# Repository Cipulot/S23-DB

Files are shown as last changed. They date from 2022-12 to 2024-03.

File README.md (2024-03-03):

# S23 DB

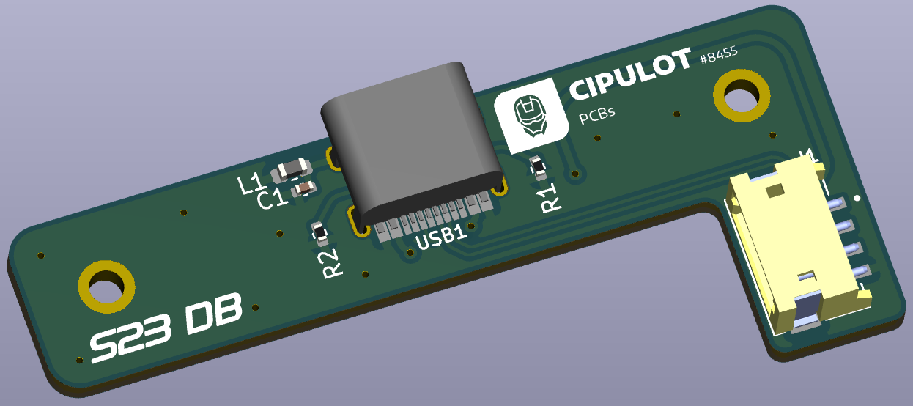
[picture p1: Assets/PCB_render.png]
S23 DB PCB render


S23 daughterboard with CC resistors.

There's not much to be said about this board. It's a daughterboard for the S23 by Sho, with the CC resistors to allow full USB-C operations.

The original JST ZH/ZR connector is replaced with one that has horizontal mount anchor points, to avoid mechanical stress on the connector (LCSC part number C485354).

The pinout is marked on the bottom of the PCB for reference.

## License

<br />This work is licensed under a <a rel="license" href="http://creativecommons.org/licenses/by-nc-sa/4.0/">Creative Commons Attribution-NonCommercial-ShareAlike 4.0 International License</a>.

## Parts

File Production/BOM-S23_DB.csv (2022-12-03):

Comment | Designator | Footprint | LCSC
HRO-TYPE-C-31-M-12 | USB1 | HRO-TYPE-C-31-M-12-Assembly | C165948
5.1k | R1,R2 | R_0402_1005Metric | C25905
100n | C1 | C_0402_1005Metric | C307331
JST | J1 | JST_S4B-ZR-SM4A-TF(LF)(SN) | C485354
220 @ 100MHz, 2A | L1 | L_0603_1608Metric | C85832

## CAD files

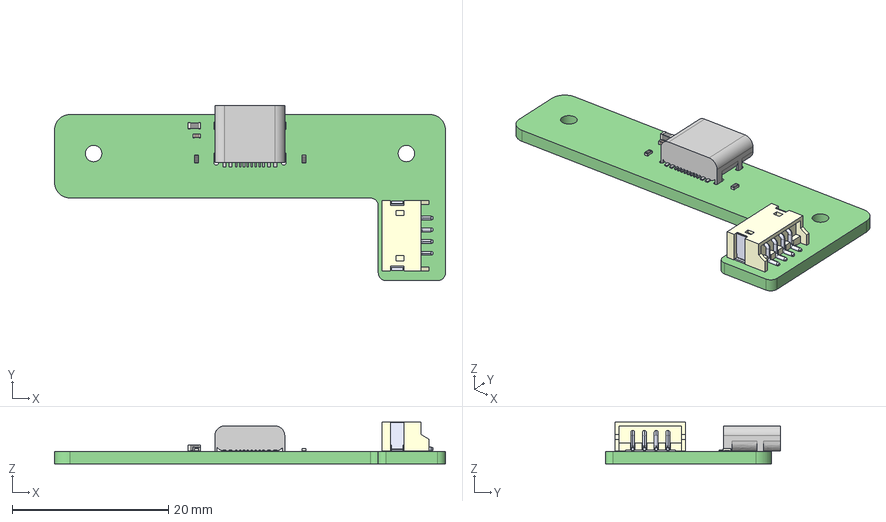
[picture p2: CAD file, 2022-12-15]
Assets/S23_DB.step
50.0 x 22.4 x 5.35 mm
S23_DB PCB

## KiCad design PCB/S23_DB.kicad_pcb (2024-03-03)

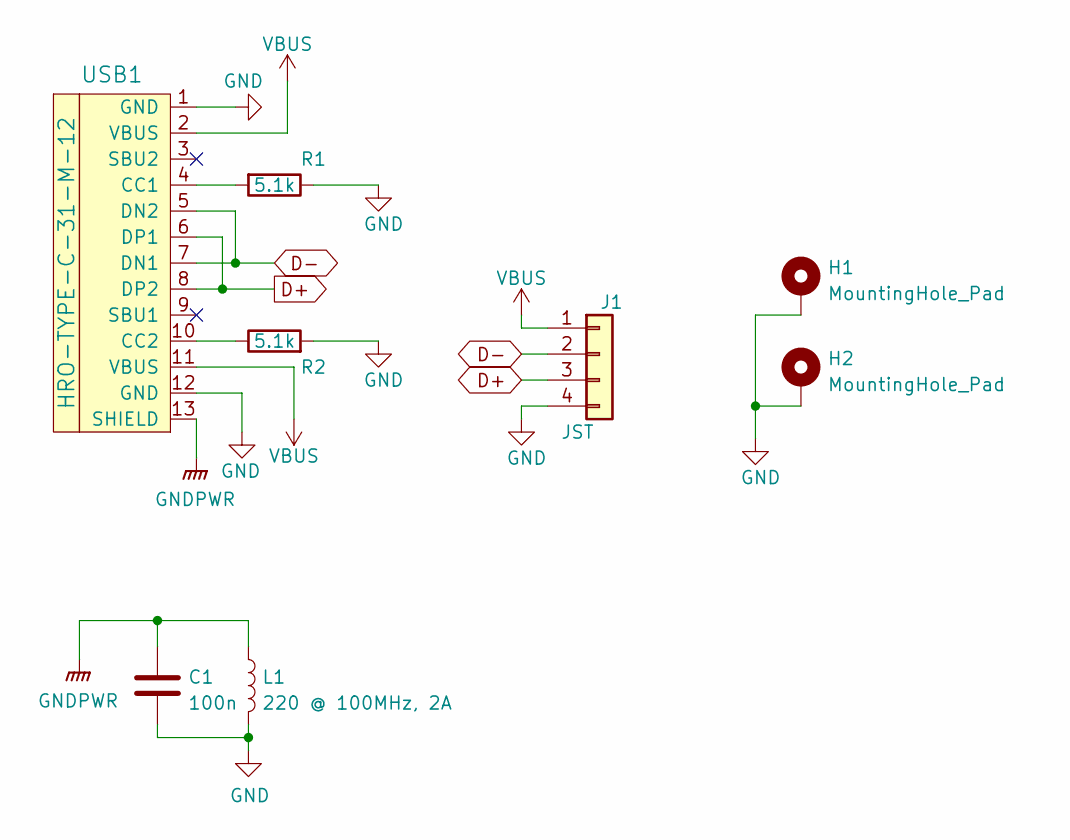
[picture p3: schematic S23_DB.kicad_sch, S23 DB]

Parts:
C1: 100n; C_0402_1005Metric; LCSC C307331
H1, H2: MountingHole_Pad; MountingHole_2.2mm_M2_ISO7380_Pad
J1: JST; JST_S4B-ZR-SM4A-TF(LF)(SN); MPN S4B-ZR-SM4A-TF(LF)(SN); LCSC C485354
L1: 220 @ 100MHz, 2A; L_0603_1608Metric; LCSC C85832
R1, R2: 5.1k; R_0402_1005Metric; LCSC C25905
USB1: HRO-TYPE-C-31-M-12; HRO-TYPE-C-31-M-12-Assembly; LCSC C165948

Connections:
D+: J1.3, USB1.6 (DP1), USB1.8 (DP2)
D-: J1.2, USB1.5 (DN2), USB1.7 (DN1)
GND: C1.2, H1.1, H2.1, J1.4, J1.S1, J1.S2, L1.2, R1.1, R2.2, USB1.1 (GND), USB1.12 (GND)
GNDPWR: C1.1, L1.1, USB1.13 (SHIELD)
unnamed: R1.2, USB1.4 (CC1)
unnamed: R2.1, USB1.10 (CC2)
VBUS: J1.1, USB1.2 (VBUS), USB1.11 (VBUS)

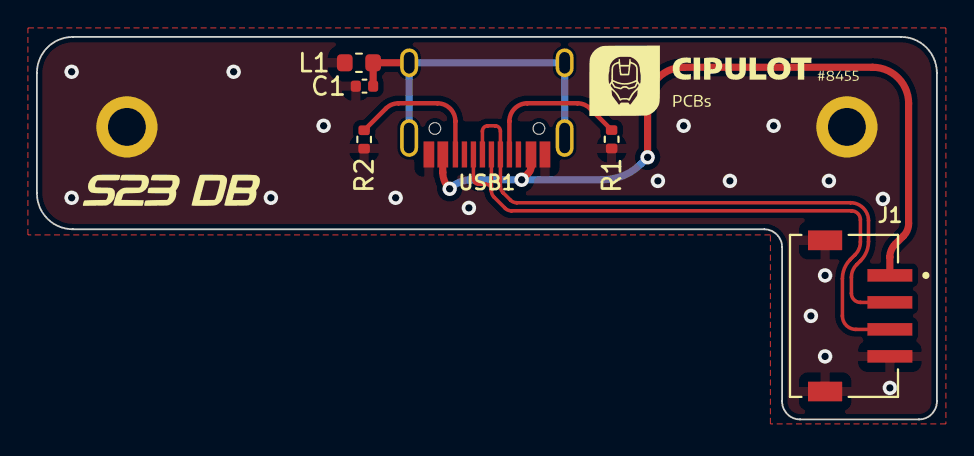
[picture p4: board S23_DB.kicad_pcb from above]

Board: 2 copper layers, 50.0 x 21.2 mm, 8 parts (0 on the bottom side), 7 nets.

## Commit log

2022-12-03 PCB project dump
    [S23_DB.kicad_pcb, S23_DB.kicad_sch]
2022-12-03 Production files dump
    [BOM-S23_DB.csv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]
2022-12-03 Update connector part for better availability.
    [BOM-S23_DB.csv, S23_DB.kicad_pcb]
2022-12-05 Fixed silkscreen order for Data lines
    [S23_DB.kicad_pcb]
2022-12-15 Added STEP model
    [S23_DB.kicad_pcb, S23_DB.step]
2023-11-17 Update sheets
    [S23_DB.kicad_pcb, S23_DB.kicad_sch]
2024-03-03 Update
    Updated the License for the project and relative details.
    [S23_DB.kicad_pcb, S23_DB.kicad_sch]

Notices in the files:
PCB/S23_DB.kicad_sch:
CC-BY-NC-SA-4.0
